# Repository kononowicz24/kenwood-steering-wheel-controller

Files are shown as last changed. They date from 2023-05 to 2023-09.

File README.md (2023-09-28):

# kenwood-steering-wheel-controller
This is a project to adapt the Audi A8 D2 FL multifunction steering wheel to be able to control a Kenwood car audio from the steering wheel controls. 
The large part of the code bases on https://init6.pomorze.pl/projects/kenwood_ford/ and was adapted to feature pin change interrupts on key presses.

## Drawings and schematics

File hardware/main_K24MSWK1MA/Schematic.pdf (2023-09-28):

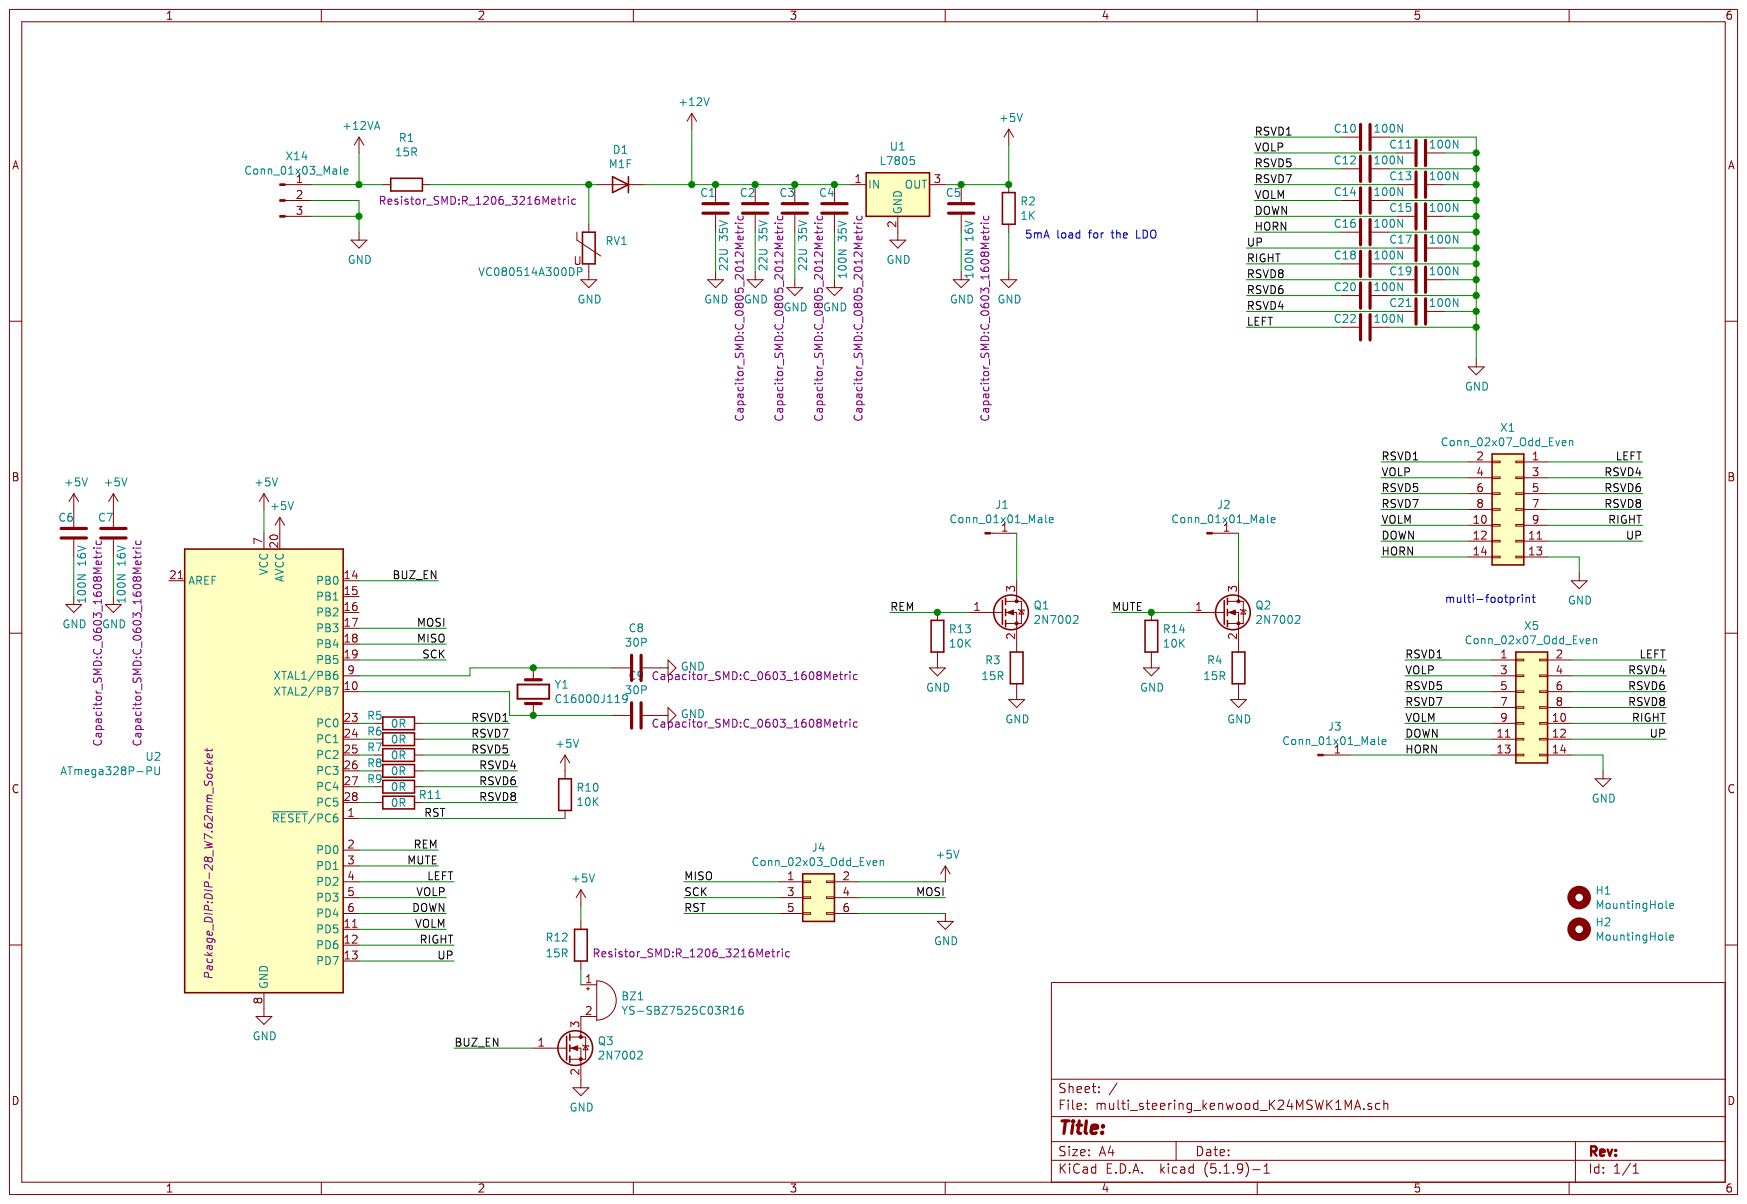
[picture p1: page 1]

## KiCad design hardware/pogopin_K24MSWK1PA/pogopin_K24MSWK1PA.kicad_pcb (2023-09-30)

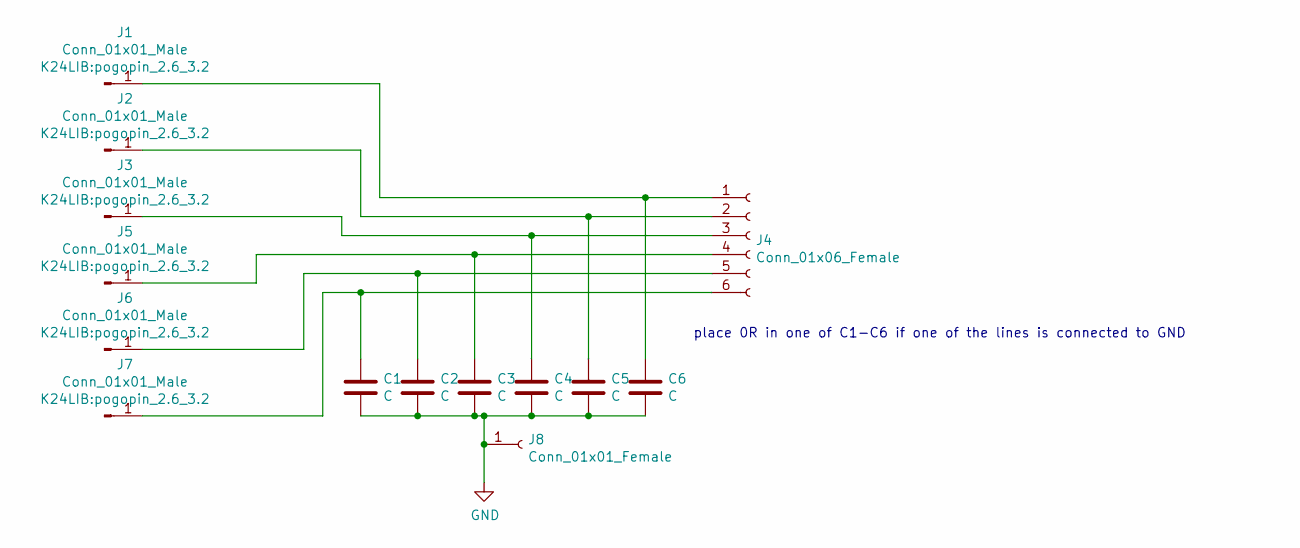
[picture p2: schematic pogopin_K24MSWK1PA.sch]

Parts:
C1, C2, C3, C4, C5, C6: C; C_0805_2012Metric
J1, J2, J3, J5, J6, J7: Conn_01x01_Male; pogopin_2.6_3.2
J4: Conn_01x06_Female; JST_PH_S6B-PH-K_1x06_P2.00mm_Horizontal
J8: Conn_01x01_Female; SolderWire-0.75sqmm_1x01_D1.25mm_OD3.5mm

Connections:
GND: C1.2, C2.2, C3.2, C4.2, C5.2, C6.2, J8.1
unnamed: C1.1, J4.6, J7.1
unnamed: C2.1, J4.5, J6.1
unnamed: C3.1, J4.4, J5.1
unnamed: C4.1, J3.1, J4.3
unnamed: C5.1, J2.1, J4.2
unnamed: C6.1, J1.1, J4.1

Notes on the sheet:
place 0R in one of C1-C6 if one of the lines is connected to GND

Board: 2 copper layers, 14 parts (0 on the bottom side), 7 nets, no tracks yet.

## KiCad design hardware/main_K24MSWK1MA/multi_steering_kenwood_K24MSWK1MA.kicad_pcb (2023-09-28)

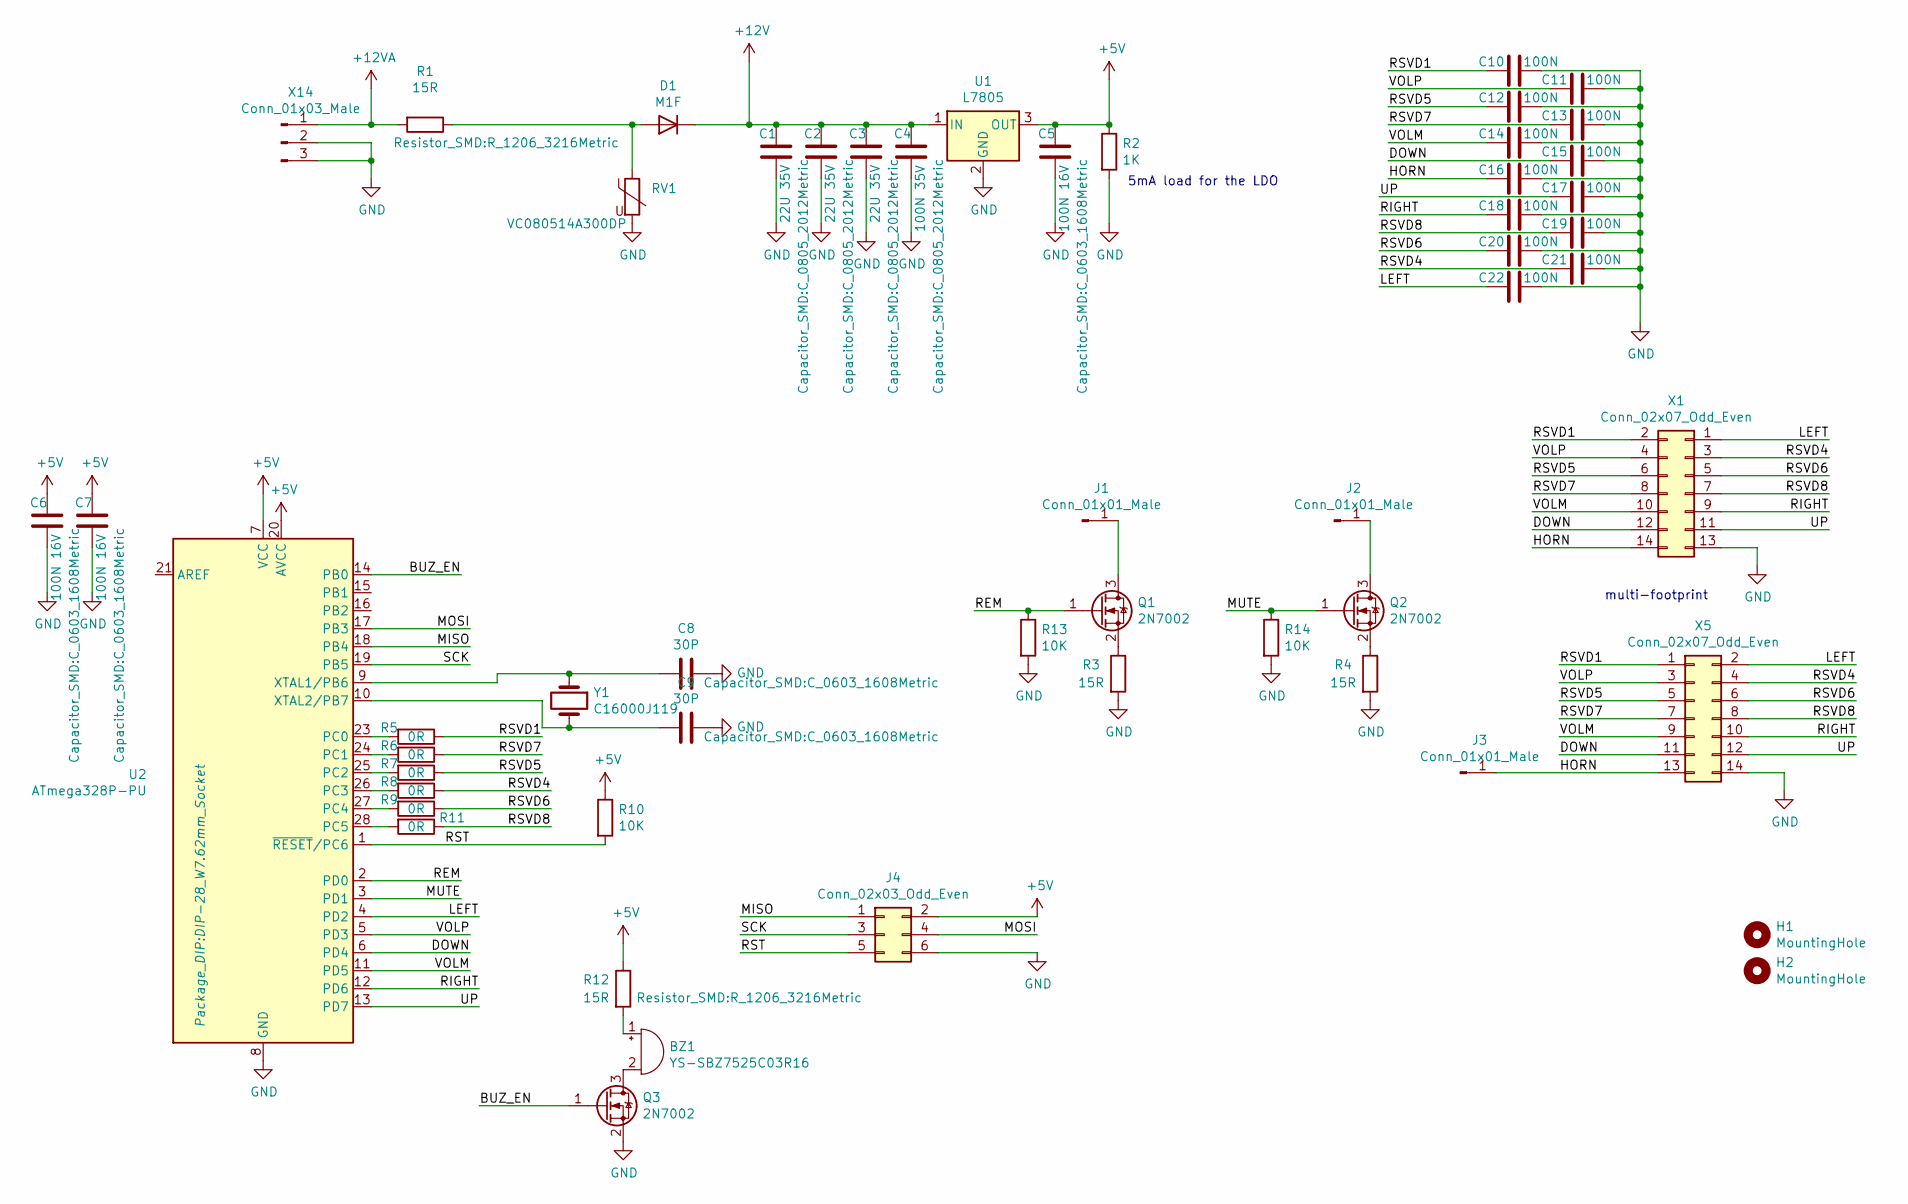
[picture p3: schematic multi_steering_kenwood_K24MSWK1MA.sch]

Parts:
BZ1: YS-SBZ7525C03R16; PUIAudio_SMT_0825_S_4_R
C1, C2, C3: 22U 35V; C_0805_2012Metric
C4: 100N 35V; C_0805_2012Metric
C5, C6, C7: 100N 16V; C_0603_1608Metric
C8, C9: 30P; C_0603_1608Metric
C10, C11, C12, C13, C14, C15, C16, C17, C18, C19, C20, C21, C22: 100N; C_0603_1608Metric
D1: M1F; D_SMA
H1, H2: MountingHole; MountingHole_3.2mm_M3
J1, J2, J3: Conn_01x01_Male; SpringContact_Harwin_S1941-46R
J4: Conn_02x03_Odd_Even; PinHeader_2x03_P2.54mm_Vertical
Q1, Q2, Q3: 2N7002; SOT-23
R1, R3, R4, R12: 15R; R_1206_3216Metric
R2: 1K; C_0603_1608Metric
R5, R6, R7, R8, R9, R11: 0R; R_0603_1608Metric
R10, R13, R14: 10K; C_0603_1608Metric
RV1: VC080514A300DP; R_0805_2012Metric
U1: L7805; TO-252-3_TabPin2
U2: ATmega328P-PU; DIP-28_W7.62mm_Socket
X1: Conn_02x07_Odd_Even; PinHeader_2x07_P2.00mm_Vertical_SMD
X5: Conn_02x07_Odd_Even; JST_PHD_B14B-PHDSS_2x07_P2.00mm_Vertical
X14: Conn_01x03_Male; PinHeader_1x03_P2.54mm_Vertical
Y1: C16000J119; Crystal_SMD_HC49-SD

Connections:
+5V: C5.1, C6.1, C7.1, J4.2, R2.1, R10.1, R12.1, U1.3 (OUT), U2.7 (VCC), U2.20 (AVCC)
+12V: C1.1, C2.1, C3.1, C4.1, D1.1 (K), U1.1 (IN)
+12VA: R1.2, X14.1
/BUZ_EN: Q3.1 (G), U2.14 (PB0)
/DOWN: C15.1, U2.6 (PD4), X1.12, X5.11
/HORN: C16.1, J3.1, X1.14, X5.13
/LEFT: C22.1, U2.4 (PD2), X1.1, X5.2
/MISO: J4.1, U2.18 (PB4)
/MOSI: J4.4, U2.17 (PB3)
/MUTE: Q2.1 (G), R14.1, U2.3 (PD1)
/REM: Q1.1 (G), R13.1, U2.2 (PD0)
/RIGHT: C18.1, U2.12 (PD6), X1.9, X5.10
/RST: J4.5, R10.2, U2.1 (~RESET~/PC6)
/RSVD1: C10.1, R5.1, X1.2, X5.1
/RSVD4: C21.1, R8.1, X1.3, X5.4
/RSVD5: C12.1, R7.1, X1.6, X5.5
/RSVD6: C20.1, R9.1, X1.5, X5.6
/RSVD7: C13.1, R6.1, X1.8, X5.7
/RSVD8: C19.1, R11.1, X1.7, X5.8
/SCK: J4.3, U2.19 (PB5)
/UP: C17.1, U2.13 (PD7), X1.11, X5.12
/VOLM: C14.1, U2.11 (PD5), X1.10, X5.9
/VOLP: C11.1, U2.5 (PD3), X1.4, X5.3
GND: C1.2, C2.2, C3.2, C4.2, C5.2, C6.2, C7.2, C8.1, C9.1, C10.2, C11.2, C12.2, C13.2, C14.2, C15.2, C16.2, C17.2, C18.2, C19.2, C20.2, C21.2, C22.2, J4.6, Q3.2 (S), R2.2, R3.2, R4.2, R13.2, R14.2, RV1.2, U1.2 (GND), U2.8 (GND), U2.22 (GND), X1.13, X5.14, X14.2, X14.3
unnamed: BZ1.1 (-), R12.2
unnamed: BZ1.2 (+), Q3.3 (D)
unnamed: C8.2, U2.9 (XTAL1/PB6), Y1.1
unnamed: C9.2, U2.10 (XTAL2/PB7), Y1.2
unnamed: D1.2 (A), R1.1, RV1.1
unnamed: J1.1, Q1.3 (D)
unnamed: J2.1, Q2.3 (D)
unnamed: Q1.2 (S), R3.1
unnamed: Q2.2 (S), R4.1
unnamed: R5.2, U2.23 (PC0)
unnamed: R6.2, U2.24 (PC1)
unnamed: R7.2, U2.25 (PC2)
unnamed: R8.2, U2.26 (PC3)
unnamed: R9.2, U2.27 (PC4)
unnamed: R11.2, U2.28 (PC5)

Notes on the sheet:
5mA load for the LDO
multi-footprint

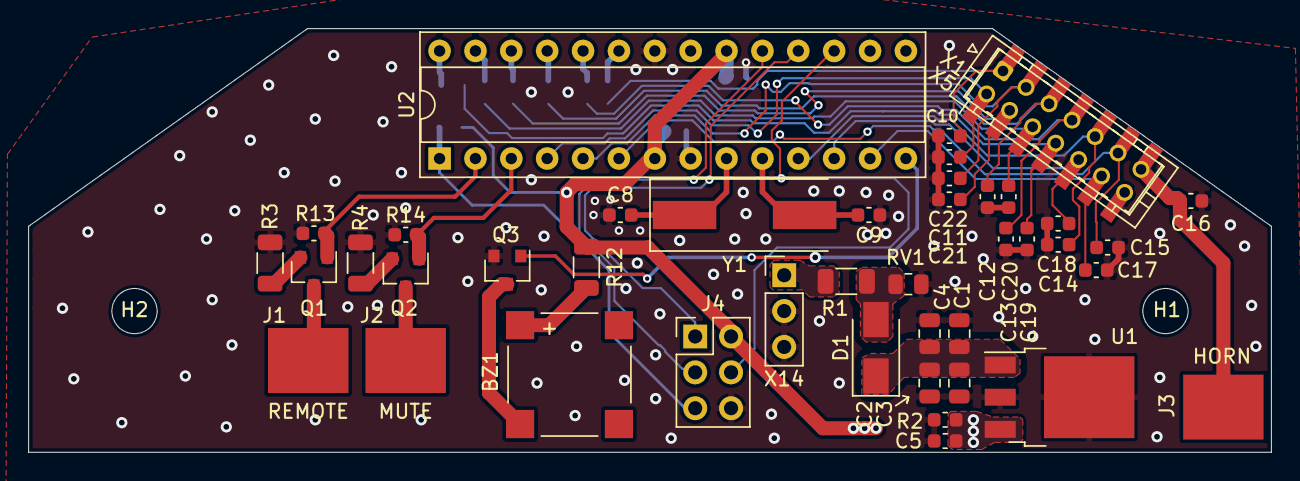
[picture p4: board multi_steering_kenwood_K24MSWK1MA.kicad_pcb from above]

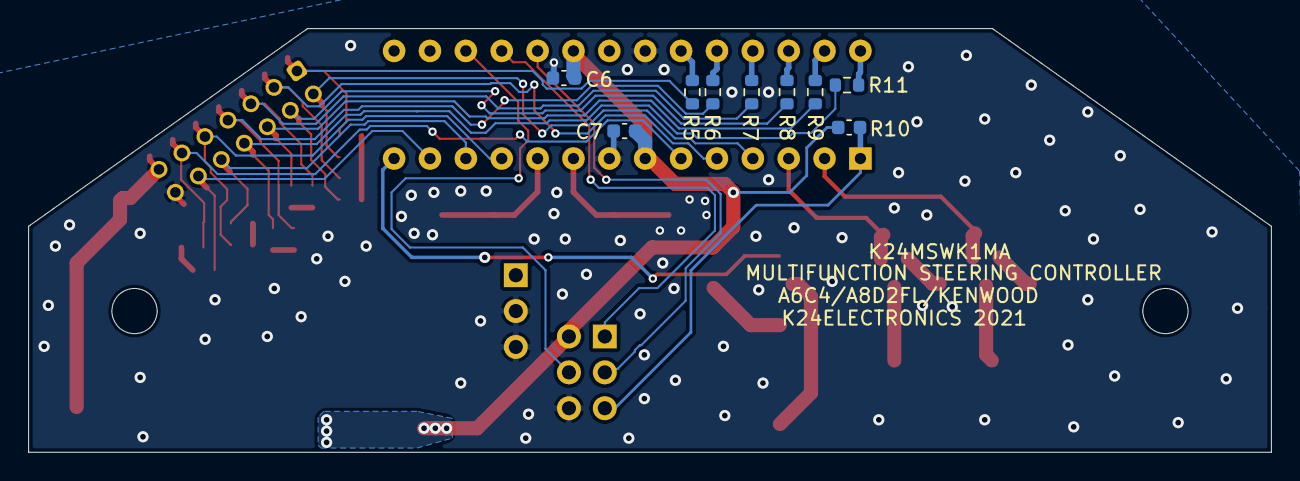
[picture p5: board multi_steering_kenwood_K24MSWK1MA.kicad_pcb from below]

Board: 2 copper layers, 88.0 x 30.0 mm, 54 parts (9 on the bottom side), 39 nets.

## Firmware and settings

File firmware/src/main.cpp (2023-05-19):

// 2023-05-19 k24: The below code was modified to be used with a custom controller and Audi A8 D2 FL steering wheel.

/* pilot1.c
 * Ford SWC to Kenwood radio (NEC protocol) adapter
 * Author: Michal Babik <michalb1981@o2.pl>
 */

#include <Arduino.h>
#include <SoftPWM.h>

SOFTPWM_DEFINE_CHANNEL(0, DDRB, PORTB, PORTB0);
SOFTPWM_DEFINE_OBJECT_WITH_PWM_LEVELS(1, 10);
//SOFTPWM_DEFINE_EXTERN_OBJECT_WITH_PWM_LEVELS(1, 10);

#define sbi(x,y) x |= _BV(y) //set bit - using bitwise OR operator
#define cbi(x,y) x &= ~(_BV(y)) //clear bit - using bitwise AND operator
#define tbi(x,y) x ^= _BV(y) //toggle bit - using bitwise XOR operator
#define is_high(x,y) (x & _BV(y) == _BV(y)) //check if the y'th bit of

#define NEC_TIME 562.5f // base time in us
#define NEC_LINE_HI 1   // pin value to set line high
#define NEC_LINE_LO 0   // pin value to set line low
#define NEC_PORT PORTD  // kenwood radio remote pin port
#define NEC_PIN PD0     // kenwood radio remote pin
#define NEC_DDR DDRD    // kenwood radio remote direction
#define BUTTONS_PIN PIND //buttons pin register

#define BTN_VOLP 0b00001000
#define BTN_VOLM 0b00100000
#define BTN_DN   0b00010000
#define BTN_UP   0b10000000
#define BTN_LH   0b00000100
#define BTN_RH   0b01000000

//#define BTN_VOLM_DN 0b00110000
//#define BTN_RH_UP   0b11000000
//#define BTN_RH_DN   0b01010000

#define CODE_VOLP 0x14
#define CODE_VOLM 0x15
#define CODE_MUTE 0x16
#define CODE_NEXT 0x0b
#define CODE_PREV 0x0a
#define CODE_FF   0x0d
#define CODE_REV  0x0c
#define CODE_SRC  0x13

void nec_set_pin (uint8_t hilo);
void nec_base (uint8_t hm, uint8_t lm);
void nec_start (void);
void nec_finish (void);
void nec_one (void);
void nec_zero (void);
void nec_8bit (uint8_t *bits);
void nec_data (uint8_t addr, uint8_t dta);
void nec_send (uint8_t data);
void beep();

uint8_t ken_code     = 0xb9;
//uint8_t count = 0;
bool locked = false;

ISR(PCINT2_vect) {
    cli();
    if ((BUTTONS_PIN & 0b11111100) == 0b11111100) {
        locked = false;
    }
    if (!(BUTTONS_PIN & BTN_VOLP)) {
        nec_send(CODE_VOLP);
    }
    if (!(BUTTONS_PIN & BTN_VOLM)) {
        if (!(BUTTONS_PIN & BTN_DN)) {
            if (locked == false) {
                nec_send(CODE_MUTE);
                locked = true;
            }
        } else {
            if (locked == false) {
                nec_send(CODE_VOLM);
                //locked = true;
            }
        }
    }

    if (!(BUTTONS_PIN & BTN_RH)) {
        if (!(BUTTONS_PIN & BTN_UP)) {
            if (locked == false) {
                nec_send(CODE_FF);
                //locked = true;
            }
        }
        if (!(BUTTONS_PIN & BTN_DN)) {
            if (locked == false) {
                nec_send(CODE_REV);
                //locked = true;
            }
        }
    }

    if (!(BUTTONS_PIN & BTN_UP)) {
        if ((BUTTONS_PIN & BTN_RH) != 0) {
            if (locked == false) {
                nec_send(CODE_NEXT);
                locked = true;
            }
        }
    }
    if (!(BUTTONS_PIN & BTN_DN)) {
        if ((BUTTONS_PIN & BTN_RH) != 0) {
            if ((BUTTONS_PIN & BTN_VOLM) != 0) {
                if (locked == false) {
                    nec_send(CODE_PREV);
                    locked = true;
                }
            }
        }
    }

    if (!(BUTTONS_PIN & BTN_LH)) {
        nec_send(CODE_SRC);
    }
    sei();
}

void setup() {
  // put your setup code here, to run once:
  //pinMode(8, INPUT); // bodge wire
  //pinMode(9, OUTPUT);//buzzer
  //TCCR1B = TCCR1B & B11111000 | B00000010; //pwm timer 1 freq = 4kHz
  //Serial.begin(115200);
  //Serial conflicts with _delay_us?
  PCICR |= 0x04; //enable pcint bank 2
  PCMSK2 |= 0xfc; //enable pcint 23-18

  DDRD = 0x03; //out 0 i 1
  PORTD = 0xFF;
  cbi (NEC_PORT, NEC_PIN); // set nec pin low

  Palatis::SoftPWM.begin(1000);

  //nec_send(0x0c);
  beep();

  //delay(1000);
  //nec_send(0x14);

  
}

void loop() {
  //delay(100);
}

void nec_set_pin (uint8_t hilo)
{
    if (hilo) sbi (NEC_PORT, NEC_PIN); // set high
    else      cbi (NEC_PORT, NEC_PIN); // set low
}
// ----------------------------------------------------------------------------
void nec_base (uint8_t hm, uint8_t lm)
{
    nec_set_pin (NEC_LINE_HI);
    for (uint8_t i=0; i<hm; ++i) 
        _delay_us (NEC_TIME);
    nec_set_pin (NEC_LINE_LO);
    for (uint8_t i=0; i<lm; ++i) 
        _delay_us (NEC_TIME);
}
// ----------------------------------------------------------------------------
void nec_start (void)
{
    nec_base (16, 8); // 9ms - 1, 4.5ms - 0
}
// ----------------------------------------------------------------------------
void nec_finish (void)
{
    nec_base (1, 0); // 562.5us - 1, 0 - 0
}
// ----------------------------------------------------------------------------
void nec_one (void)
{
    nec_base (1, 3); // 562.5us - 1, 1.6875us - 0
}
// ----------------------------------------------------------------------------
void nec_zero (void)
{
    nec_base (1, 1); // 562.5us - 1, 562.5us - 0
}
// ----------------------------------------------------------------------------
void nec_8bit (uint8_t *bits)
{
    for (uint8_t i=0; i<8; ++i) {
        if (*bits & 0x01)
            nec_one ();
        else
            nec_zero ();
        *bits = *bits >> 1;
    }
}
// ----------------------------------------------------------------------------
void nec_data (uint8_t addr, uint8_t dta)
{
    uint8_t naddr = ~addr;
    uint8_t ndta  = ~dta;
    nec_8bit (&addr);
    nec_8bit (&naddr);
    nec_8bit (&dta);
    nec_8bit (&ndta);
}

void nec_send (uint8_t data) {
  //cbi (NEC_PORT, NEC_PIN); // set nec pin low
  nec_start();
  nec_data(ken_code, data);
  nec_finish();
  //cbi (NEC_PORT, NEC_PIN); // set nec pin low
}

void beep() {
  Palatis::SoftPWM.set(0, 5);
  delay(50);
  Palatis::SoftPWM.set(0, 0);
}

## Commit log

2023-09-28 update .gitignore for Kicad
2023-09-28 Added main PCB HW design files (rev.A)
    [multi_steering_kenwood_K24MSWK1MA-B_Cu.gbr, multi_steering_kenwood_K24MSWK1MA-B_Mask.gbr, multi_steering_kenwood_K24MSWK1MA-B_Paste.gbr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]
2023-09-28 rename folders, set up pogopin board project
    [multi_steering_kenwood_K24MSWK1MA-B_Cu.gbr, multi_steering_kenwood_K24MSWK1MA-B_Mask.gbr, multi_steering_kenwood_K24MSWK1MA-B_Paste.gbr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]
2023-09-30 finished sch, started components layout
    [pogopin_K24MSWK1PA.kicad_pcb, pogopin_K24MSWK1PA.sch]
